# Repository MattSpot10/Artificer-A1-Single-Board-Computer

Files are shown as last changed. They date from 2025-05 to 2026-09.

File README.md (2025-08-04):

# Artificer A1 Single Board Computer
 An open source single board computer with AI capabilities. (Still in progress)

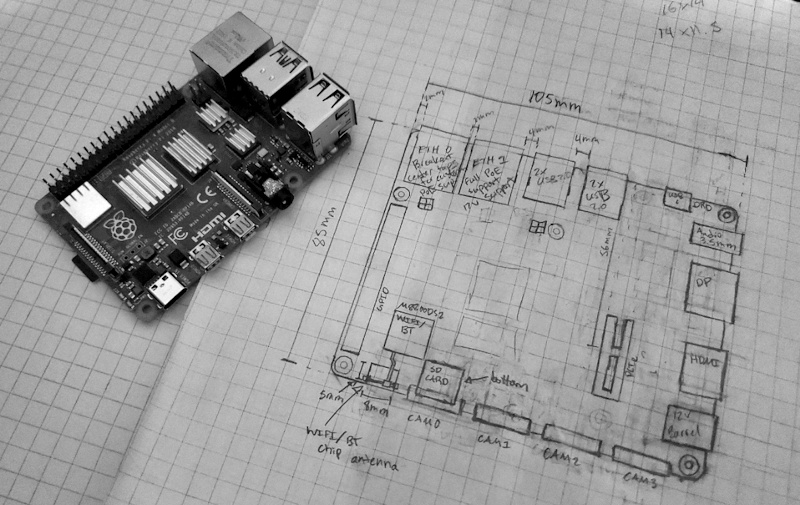
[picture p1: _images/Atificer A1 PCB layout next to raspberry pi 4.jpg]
SBC IMG
 

### **Features/Capabilites
- Alliwnner T527 SoC (Octa-core ARM Cortex-A55, up to 1.8 GHz)
- 4GB LPDDR4 SDRAM
- Dual Gigibit Ethernet (RJ45 ports capable of PoE)
- PCIe gen 2.1
- Display Port, HDMI, 2x4 lane MIPI DSI
- 4x2 lane MIPI CSI
- SD Card as boot media
- M8800DS2 Wifi/BT module with onboard PCB antenna
- 12V 5.5mm barrel jack power input
- 2x20 raspberry pi GPIO header
- 3.5mm sterio audio, mic
- 4xUSBA 2.0
- 1xUSBC 2.0 DRD

### **Progress/Plans (Since Jan 2025)**
**V1 Schematic capture**
- Done: Component choice, symbol, and footprint creation. Finished interconnects for Ethernet, USB, MIPI DSI & CSI, SDRAM, PCIe
- Todo: Interconnects for power, audio, gpio, I2C interfaces, wifi&bt, SD card.
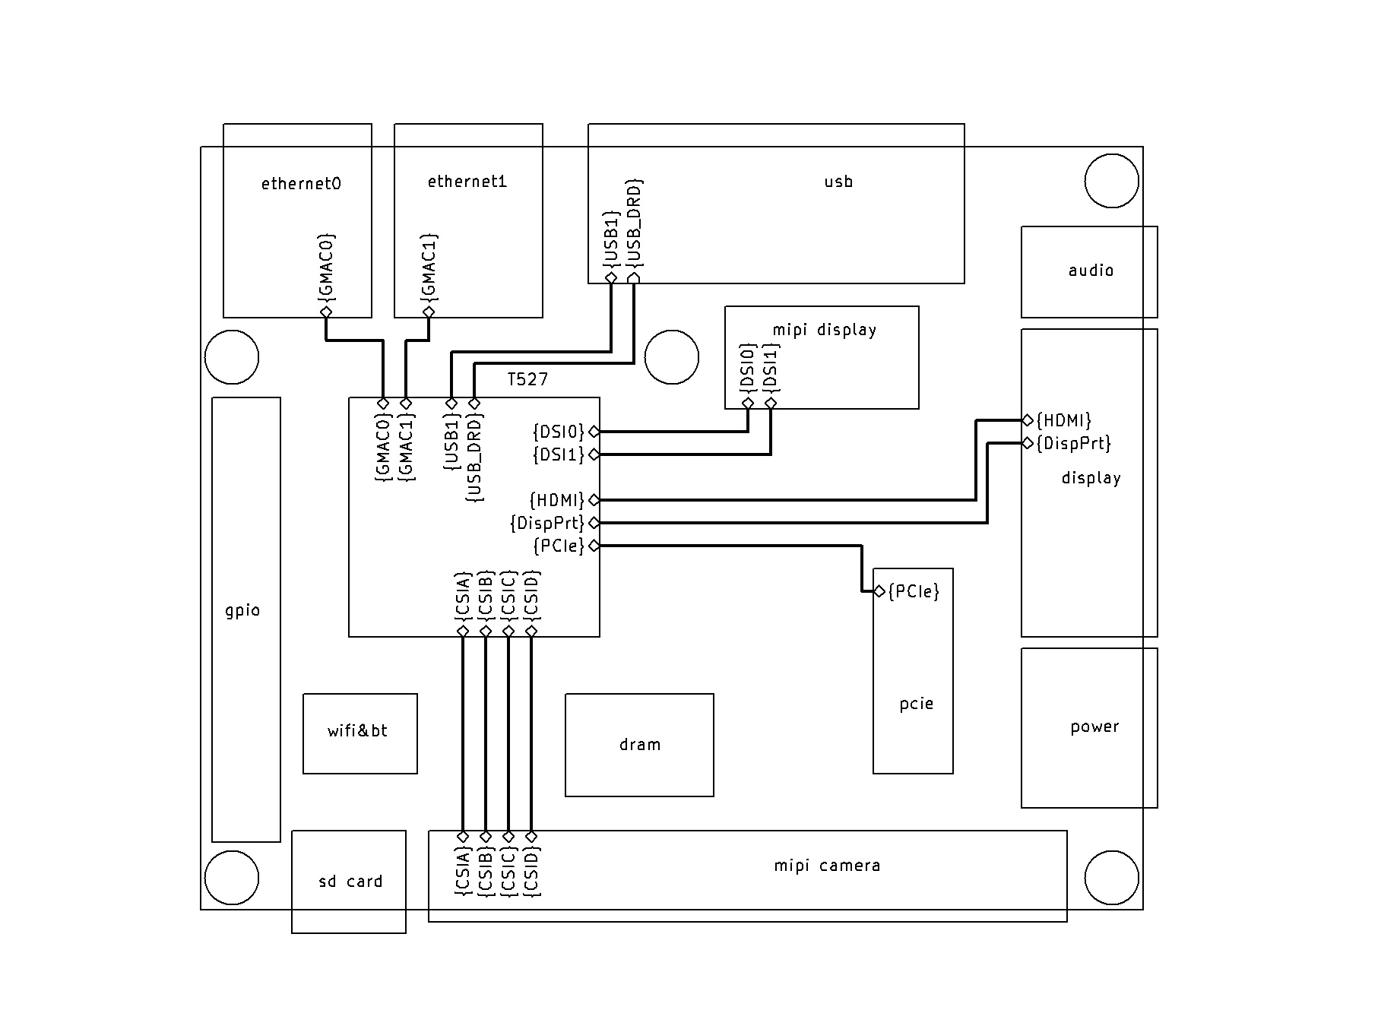
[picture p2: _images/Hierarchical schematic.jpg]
Hierarchical schematic


**PCB Compatabilites**

The Allwinner T527 is a 0.5mm pitch BGA requiring these compatabilities for maufacturing:
- 3mil trace
- 3mil spacing
- 10.685mil pad
- 6mil drill
- 10.685mil pad - 6mil drill = 2.342mil anular ring
- 6 - 8 layers (Stackup and material not determined)

**Booting Linux**
- Add Spi flash chip to schematic for holding U Boot.
- Configure U Boot for loading the Linux kernel and the device tree blob.

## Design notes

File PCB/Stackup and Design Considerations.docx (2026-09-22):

Stackup

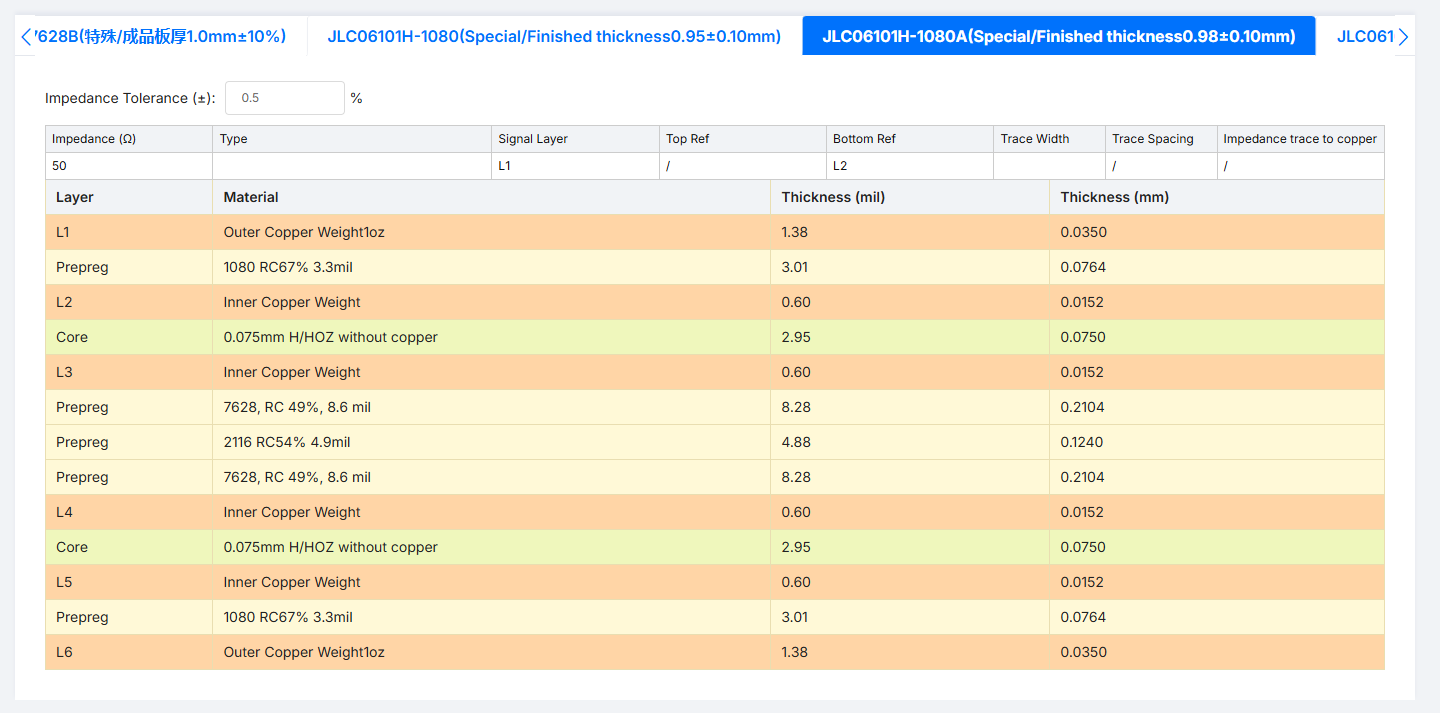
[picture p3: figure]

https://jlcpcb.com/pcb-impedance-calculator

Impedance (Ω) | Purpose | Type | Signal Layer | Top Ref | Bottom Ref | Trace Width | Trace Spacing | Impedance trace to copper
85 | Top Layer 85ohm… | Differential Pair (Non coplanar) | L1 | / | L2 | 4.08 | 4.2 | /
90 | | Differential Pair (Non coplanar) | L1 | / | L2 | 4.05 | 5.5 | /
85 | | Differential Pair (Non coplanar) | L3 | L2 | L5 | 4.03 | 5 | /
50 | | Single Ended (Non coplanar) | L1 | / | L2 | 4.31 | / | /
48.88 | | Single Ended (Non coplanar) | L3 | L2 | L5 | 4 | / | /

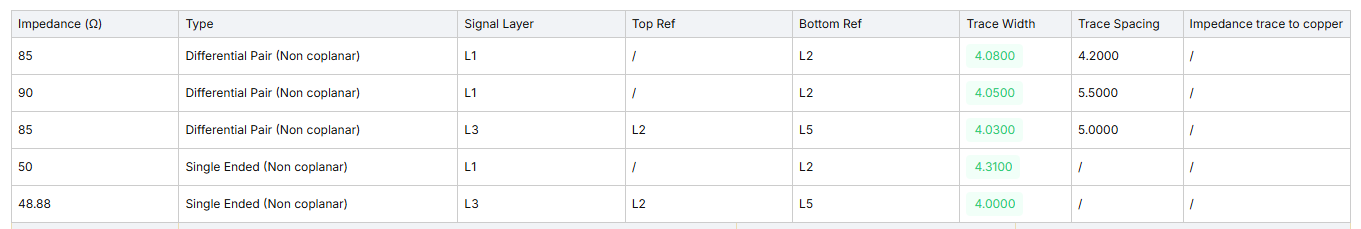
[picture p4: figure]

Protocol | Layer | Trace Width | Trace Spacing | Target Single | Target Diff
MIPI CSI, DSI | L1/L6 | 4.31mil | 6.4mil | 50ohm | 90ohm
USB 3.1, USB 2.0, SuperSpeed & PCIe, HDMI, DP, DDR4 Differential | L1/L6 | 4.02mil | 5.4mil | - | 90ohm
DDR4, RGMII, SDMMC | L1/L6 | 4.31mil | - | 50ohm | -
DDR4, RGMII, SDMMC | L3/L4 | 4.0mil | - | 48.88ohm

Protocol | Layer | Trace Width | Trace Spacing | Target Single | Target Diff
90ohm diff 50ohm single | L1/L6 | 4.31mil | 6.4mil | 50ohm | 90ohm
USB 3.1, USB 2.0, SuperSpeed & PCIe, HDMI, DP, DDR4 Differential | L1/L6 | 4.02mil | 5.4mil | - | 90ohm
DDR4, RGMII, SDMMC | L1/L6 | 4.31mil | - | 50ohm | -
DDR4, RGMII, SDMMC | L3/L4 | 4.0mil | - | 48.88ohm

For non-coplanar keep trace spacing between neighboring traces 3 times the width apart if measuring from the center. This means trace spacing would be equal 2x the trace width.

50ohm single ended non coplanar (top layer):

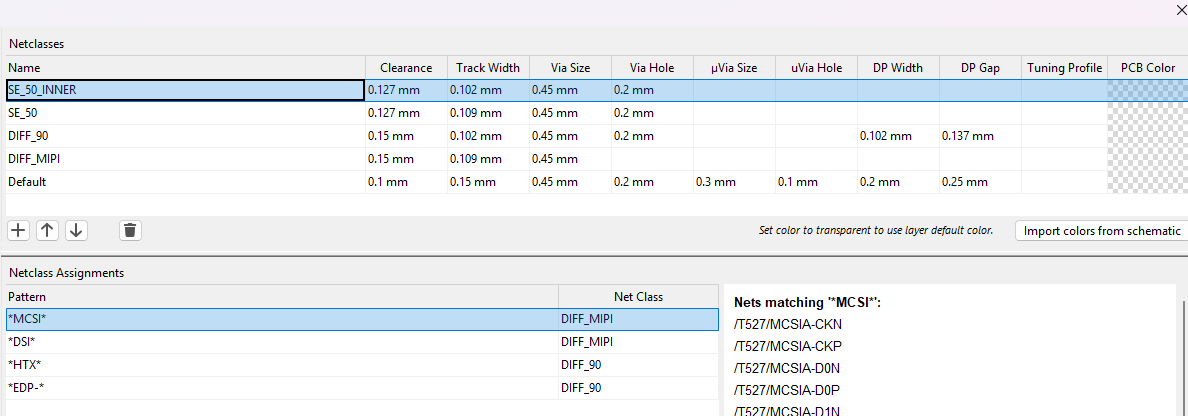
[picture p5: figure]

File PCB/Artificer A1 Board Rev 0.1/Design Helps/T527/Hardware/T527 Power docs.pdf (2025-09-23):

修改记录
版本 | 修改内容 | 日期 | 制/修定人 | 备注
V1.0 | Initial version | 20231031 | AWA1962

## AXP717B+AXP323 For车载后装,商显,工控

CHIP | 编 号 | 分路名称 | INPUT | 电压/电流范围 | 电压 | 启动时序 | 需求电压 （V） | 需求电流 (mA)
（上电默认状 | | | | SOC | Flash & DRAM | DEVICE
| 1 | RTCLDO | 4V-PS | 3.3/1.8/30mA | 1.8V(ON) | 常开 | 1.8 | 10 | VCC-RTC | | | ON | ON | ON
| 2 | CPUSLDO | DCDC3 | 0.5-1.4V/30mA 50mVstep | 0.9V(ON) | 1 | 0.9 | 20 | VDD-CPUS VDD09-USB（预留） | | | ON | ON | OFF | VDD09-USB预留USB STANDBY方 案；
| 3 | DCDC1 | 4V-PS | 0.5~1.54V/4A 10/20mVstep
| | DCDC2 | | 0.5~3.4V/3A 10/20/100mVstep | 0.9V(ON) 0.9V(ON) | 1 1 | 0.9~1.15 0.9 | 4000 2670 | VDD_CPU_L VDD-SYS VDD-HDMI VDD-GPU VDD-VE VDD-DE VDD09-USB VDD-PCIE VDD-EDP | | | ON ON | OFF OFF | OFF 4 OFF | VDD09-USB默认super standby方 案，待机时掉电；
| 5 | DCDC3 | | 0.5~1.84V/1.5A 10/20mVstep | 1.1V(ON) | 1 | 1.1V /1.2/1.35/1.5
| | DCDC4 | | 1~3.7V/3A 100mVstep | 3.3V(OFF) | OFF | 3.3 | 1200 2510 | VCC-DRAM VCC-PD VCC-PE VCC-PK VCC-PJ VCC-PI VCC33-USB-2 (USB3.0) | VCC-DRAM | VCC-3V3 VCC-3V3-WIFI VCC-3V3-PCIE VCC3V3-GPHY LTE-PWR（预留） VCC-CTP VCC-LCD0 VCC-LCD1 VCC-3V3-DEV | ON ON | ON OFF | OFF 6 OFF 3.3V for normal use VCC-3V3下挂 | RS232/RS485/GPS/USBHUB/ DSP/CODEC/EDP/HDMI对片，耗电 约500mA
| | ALDO2 | 固定 4V-PS | 0.5~3.5V/0.4A 100mVstep | 1.8V(OFF) | OFF | / | / | Reserve | | | OFF | OFF | OFF 8
| 7 | ALDO1 ALDO3（该路1% 精度，其他2%） | | 0.5~3.5V/0.5A 100mVstep | 1.8V(OFF) | OFF | / | / | Reserve | | | OFF | OFF | OFF 9
| | | | 0.5~3.5V/0.2A 100mVstep | 3.3V(ON) | 3 | 3.3 | 50 | VCC-PL VCC-PM（预留） VCC33-USB （预留） | | | ON | ON | OFF 3.3V for STBY | VCC33-USB (USB2.0)预留USB standby方案；
| 10 ALDO4（该路1% 精度，其他2%） | | | 0.5~3.5V/0.4A 100mVstep | 1.8V(ON) | 1 | 1.8 | 125 | AVCC VCC-PLL VDD18-DRAM VCC-ADC VCC-DCXO | | | ON | OFF | OFF 1.8V for 1% | ADC接口的VREFP上电时序需晚于或 等于AVCC上电时序。默认方案， VREFP在die内连接到AVCC
| 1.8 v | BLDO1 | 4V-PS | 0.5~3.5V/0.5A 100mVstep | 1.8V(OFF) | OFF | 1.8 | 150 | VCC-PG VCC-PM | | VCCIO-WIFI | ON/OFF OFF | | OFF 12 BLDO2
| | | | 0.5~3.5V/0.2A 100mVstep | 1.8V(ON) | 1 | 1.8 | 20 | | VDD18-LPDDR | | ON | ON | OFF 1.8V for DDR
| 13 BLDO3 | | | 0.5~3.5V/0.5A 100mVstep | 2.8V(OFF) | OFF | 1.8 | 225 | CPVIN VCC-PE（预留） VCC-PD（预留） VCC-PJ（预留） VCC-PK（预留） VCC-MCSI VCC-HDMI VCC18-PCIE VCC18-EDP | | VCC-1V8-AUDIO | ON | OFF | OFF 1.8V for normal use
| 14 BLDO4 | | | 0.5~3.5V/0.4A 100mVstep | 1.2V(OFF) | OFF | 1.8 | 30 | VCC-PL（预留） | | | ON | ON | OFF 1.8V for STBY 15 CLDO1
| | | 4V-PS | 0.5~3.5V/0.5A 100mVstep | 1.8V(ON) | 2 | 1.8 | 450 | VCC-PC VCC-LVDS0 VCC-LVDS1 | VCC-EMMC（预留） VCC-PC(VCCQ- EMMC) | | ON | OFF | OFF 1.8V for normal use
| 16 CLDO2 | | | 0.5~3.5V/0.4A 100mVstep | 3.3V(OFF) | OFF | 1.8 | 105 | VCC-EFUSE | | | OFF | OFF | OFF | EFUSE电源仅可在烧录时打开；
| 17 CLDO3 | | | 0.5~3.5V/0.5A 100mVstep | 3.3V(ON) | 3 | 3.3 | | VCC-IO VCC-PC（预留） VDD33 VCC33-USB | VCC-CARD VCC-SPIFLASH VCC-EMMC VCC-NAND | | OFF | OFF | OFF | VCC33-USB (USB2.0)默认super standby方案，待机时掉电；
| 18 CLDO4 | | | 0.5~3.5V/0.5A 100mVstep | 3.3V(OFF) | OFF | / | / | Reserve | | | OFF | OFF | OFF AW1890 19 集成ALDO
| | (1%精度) | VDD33 | 1.8V | 1.8V(ON) | / | 1.8 | 50 | AVCC（预留） | | | ON | OFF | OFF | SOC内部LDO输出，预留1.8V使用
A X P 3 2 3 | 20 DCDC1 | | 4V-PS | 0.5~3.4V/1.5A 10/20/100mVstep | 0.9(ON) | 1注 | 0.9~1.18 | 4000 | VDD_CPU_B | | | ON | OFF | OFF 21 DCDC2
| | | 4V-PS | 0.5~1.54V/2.5~3A 10/20mVstep | 0.9(ON) | 1注
| 22 DCDC3 | | 4V-PS 4V-PS | 0.5~1.84V/2A 10/20mVstep | 0.9(ON) | 1注 | 0.9 | 1650 | VDD-DNR | | | ON | OFF | OFF 23 RTCLDO
| | | 4V-PS | 1.8V/2.5V/2.8V/3.3V /0.03A | OFF | OFF | | / | | | | ON/OFF OFF | | OFF 24 ALDO1
| | | 4V-PS | 0.5~3.5V/0.3A 100mVstep | 1.8V(OFF) | OFF | 1.8 | / | | | | OFF | OFF | OFF 25 DLDO1
| | | | 0.5~3.5V/0.5A 100mVstep
用途 | Normal Work | Super Standby 关机 | 注释 | 各场景应用说明

A
X
P
7
1
7
3.3V(OFF) | OFF | 3.3 | 350 | VCC-FM | ON/OFF OFF | OFF 以下应用需要需要外挂电源
外挂 电源 | 26 外挂 | Buck5VOUT （SA24403/ SYQA303） | DCIN-12V 4.5~5.5V/3A | 5V(ON) | / | 5 | 3000 | PMU-DCIN VCC-5V（预留） | ON | ON | OFF 27 外挂
| | DCDC5V （SA24403/ SYQA303） | DCIN-12V 5V/3.5A | 5V(ON) | / | 5 | 2000 | VCC-5V AMP-5V HDMI-5V USB-5V | ON | OFF | OFF SER/DES/AMP/CAN
| 28 外挂 | DCDC3.3V （SY8089） | VCC-5V 1.2V/2A | 1.2V(ON) | / | 1.2 | 1000 | DVDD-1V2-CSI0 DVDD-1V2-CSI1 AVDD-1V2-CSI0 AVDD-1V2-CSI1 | ON | OFF | OFF 29 外挂
| | DCDC3.8V （SA24403/ SYQA303） | DCIN-12V 3.3V/3.5A | 3.3V(OFF) | / | 3.3/3.8 | 1000 | LTE-PWR | ON | OFF | OFF 4G模块
| 30 外挂 | LDO1.8V /SGM2028-ADJ) (RY6211B-18C | LTE-PWR 1.8V/0.5A | 1.8V(OFF) | / | 1.8 | 100 | VCC-LTE18 | ON | OFF | OFF 4G模块
| 31 外挂 | LDO3.3V （mpq2029） | DCIN-12V 3.3V/0.45A | 3.3V(ON) | / | 3.3 | 100 | 3V3-STBY (VCC-MCU) | ON | ON | ON | 3V3-STBY 32 外挂
| | LDO1.8V /SGM2028-ADJ) (RY6211B-18C | 3V3-STBY 1.8V/0.5A | 1.8V(ON) | / | 1.8 | 10 | 1V8-STBY
(VCC-RTC) | ON | ON | ON | 1V8-STBY 注：AXP323上电使能是由AXP717B-BLDO2提供，该时序为AXP323使能之后的启动时序

注：灰色字体的电源代表预留方案

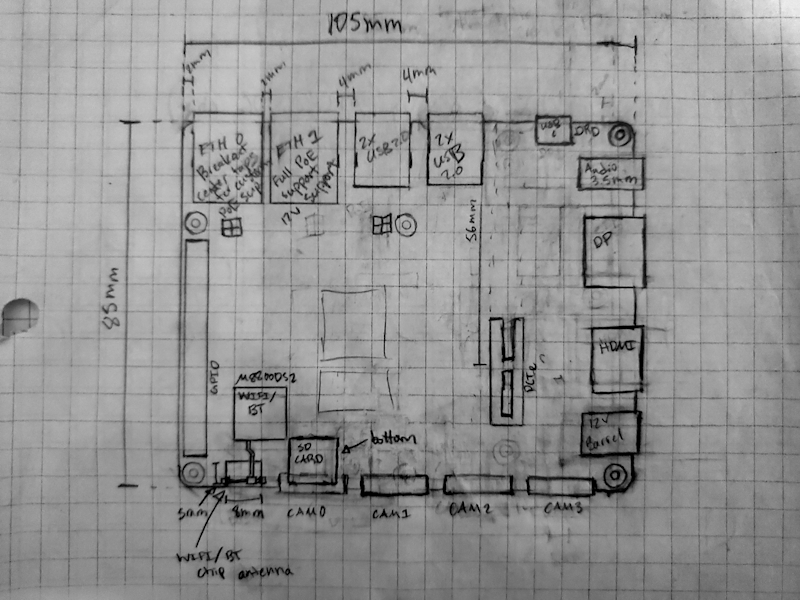
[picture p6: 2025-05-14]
_images/Atificer A1 PCB layout.jpg

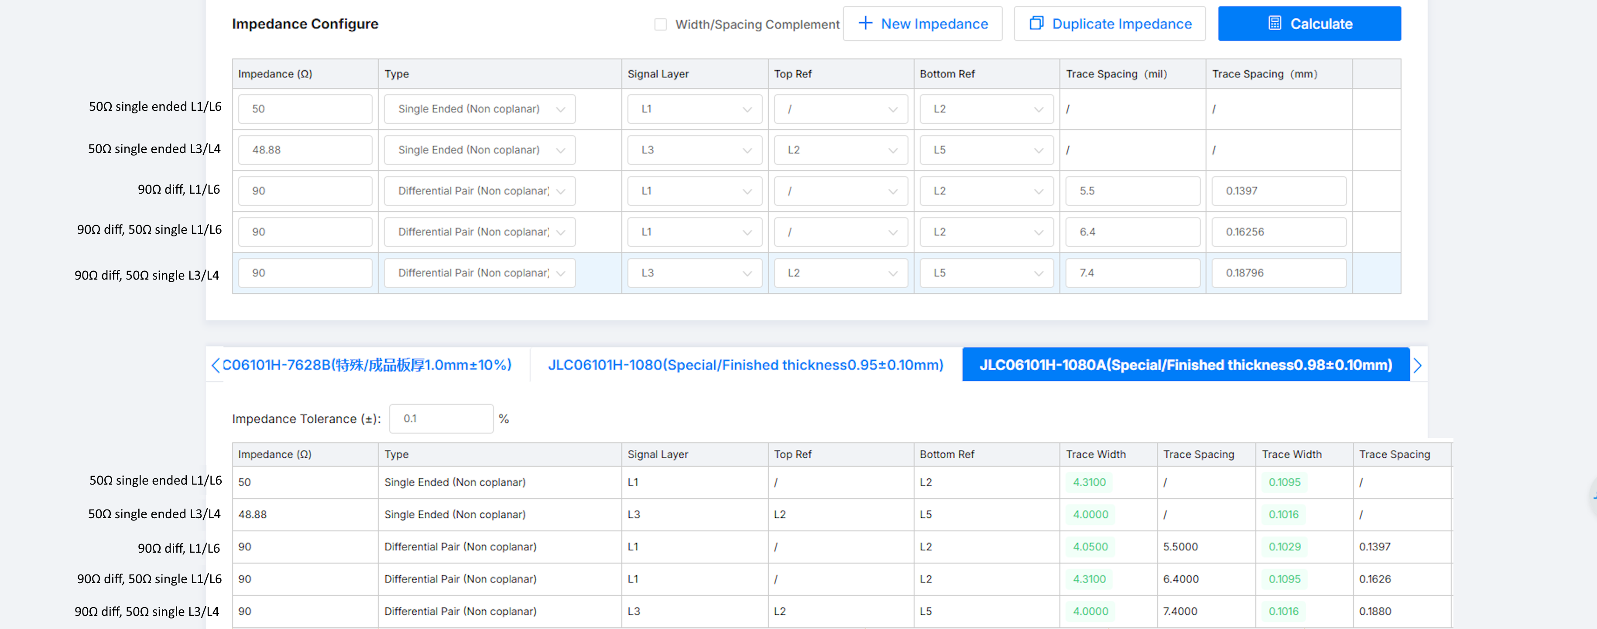
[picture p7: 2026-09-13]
PCB/Impedance-2.png

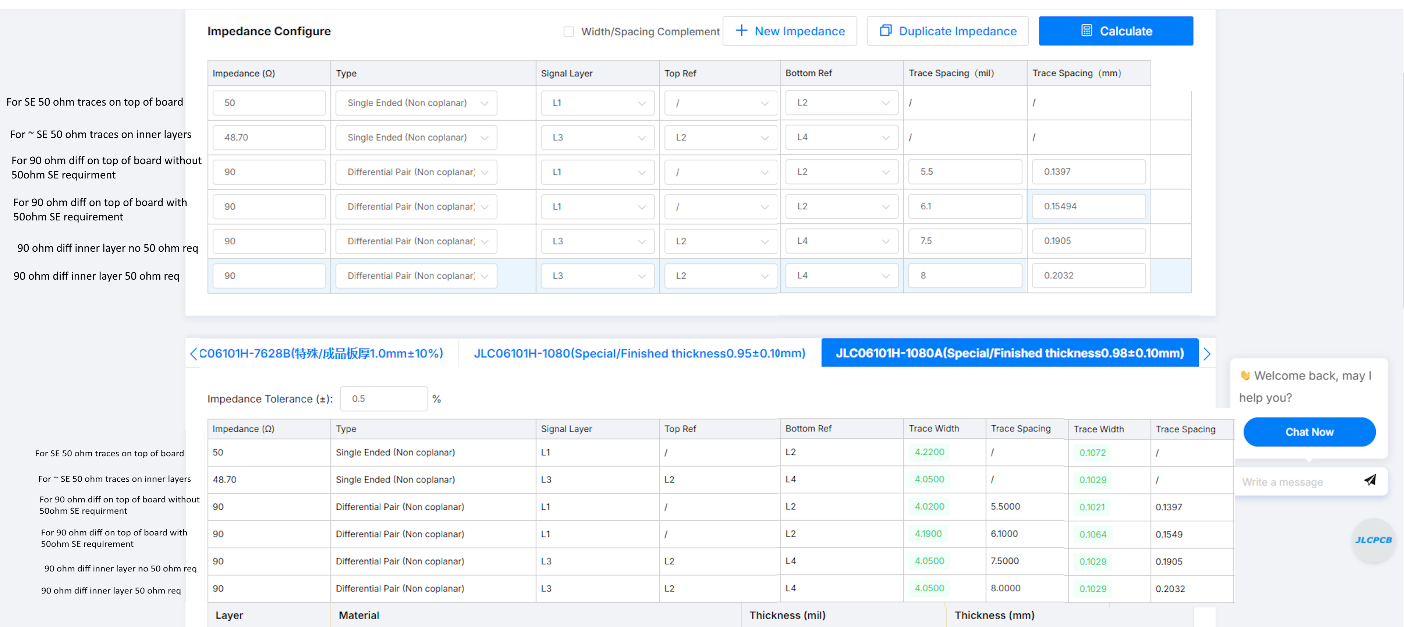
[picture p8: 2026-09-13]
PCB/Impedance.png

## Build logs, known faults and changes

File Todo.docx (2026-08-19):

Connect TWI interfaces: Camera, PMIC, Display, GPIO

Connect UART interfaces: USB C, GPIO

Figure out Headphone usage.

Figure out what to do with unused pins.

Find out impedance values for high-speed traces and place that on the schematic

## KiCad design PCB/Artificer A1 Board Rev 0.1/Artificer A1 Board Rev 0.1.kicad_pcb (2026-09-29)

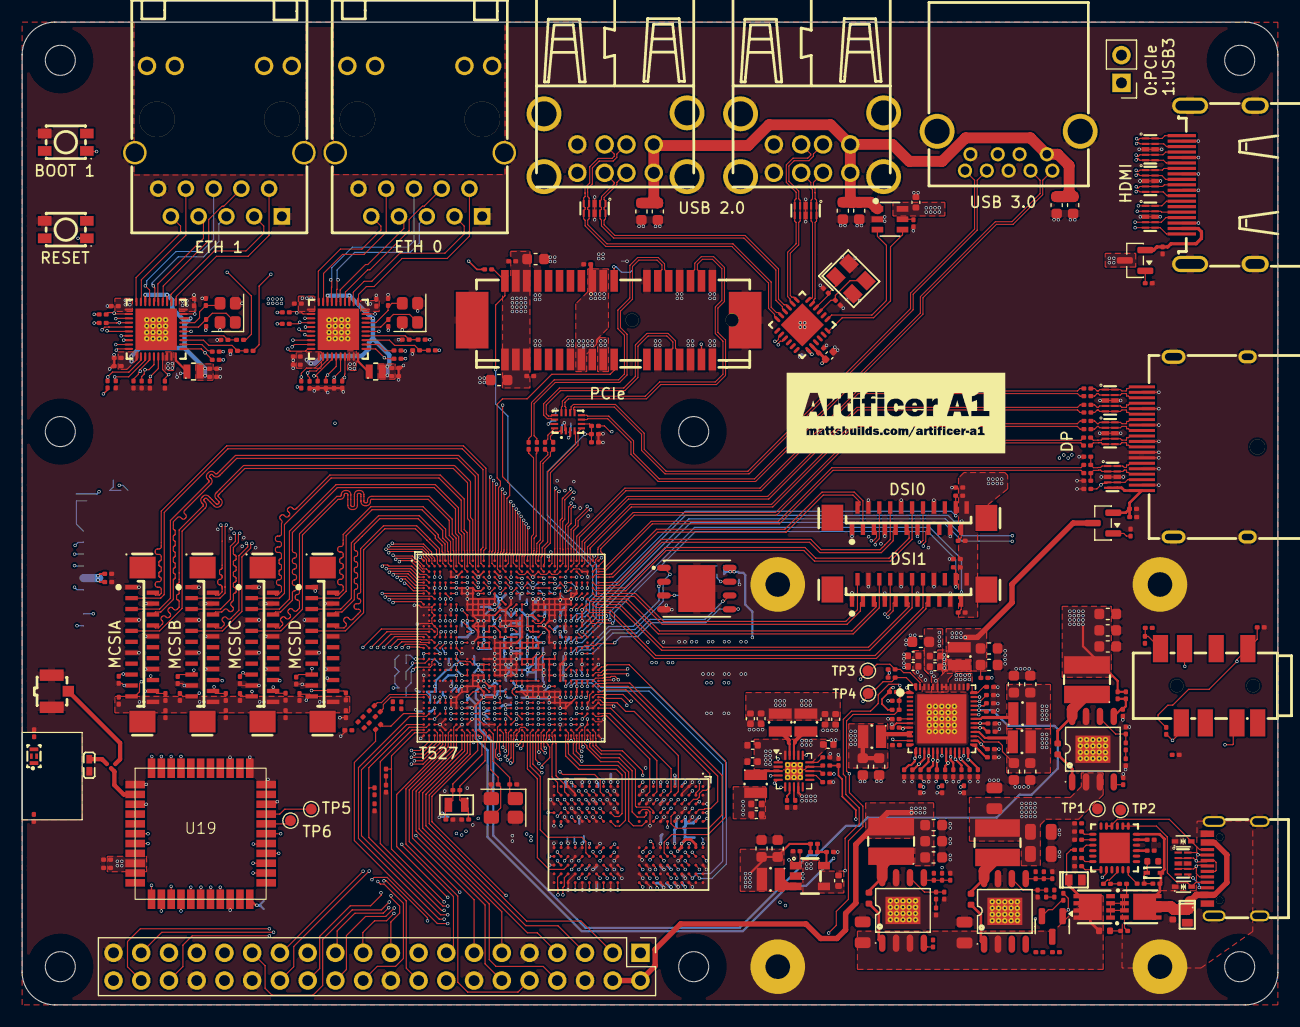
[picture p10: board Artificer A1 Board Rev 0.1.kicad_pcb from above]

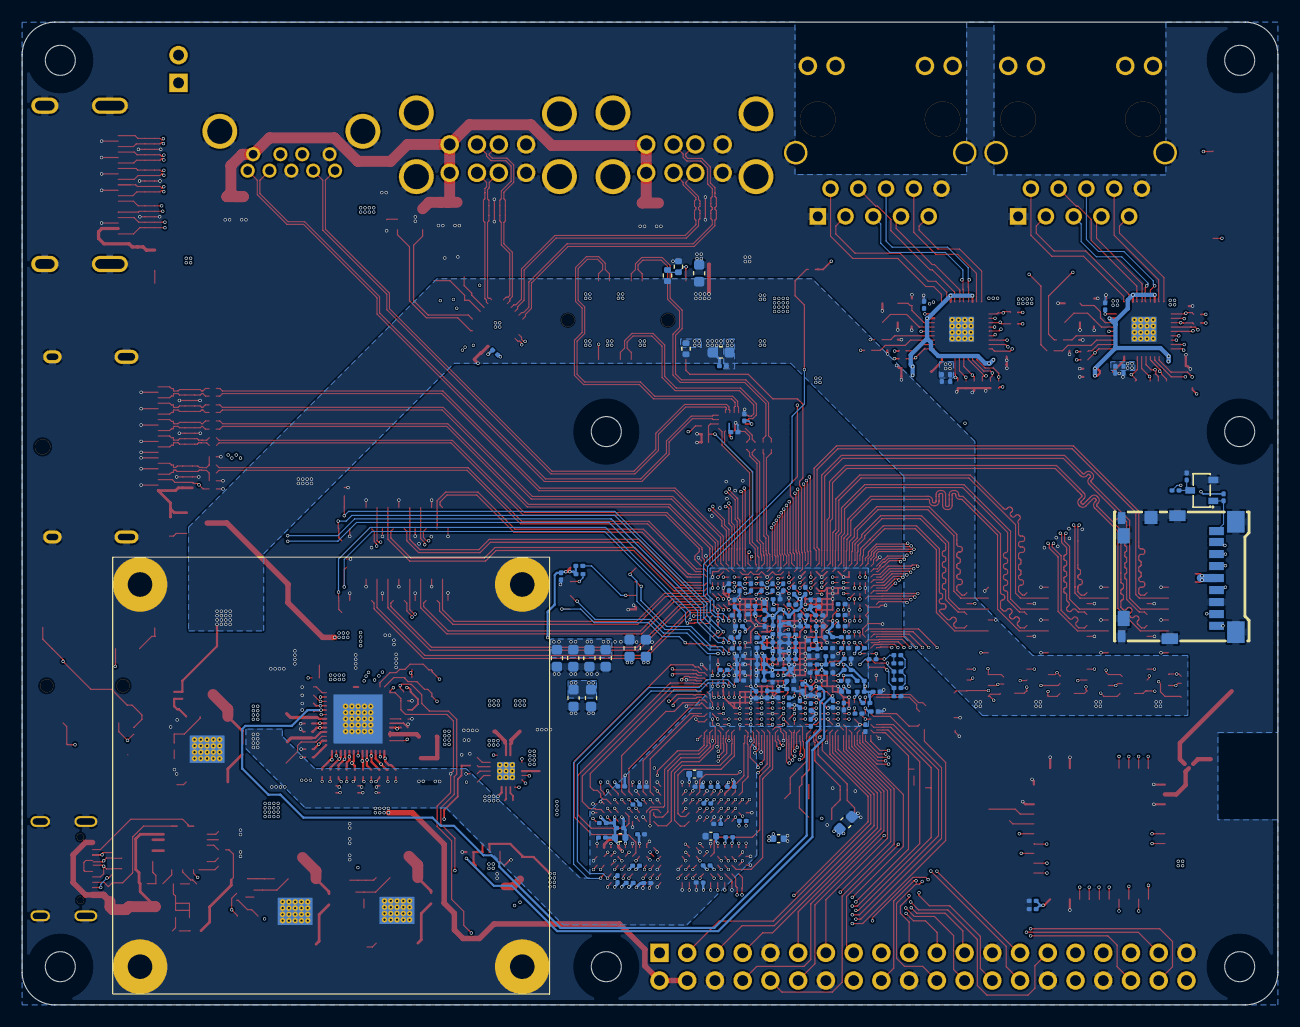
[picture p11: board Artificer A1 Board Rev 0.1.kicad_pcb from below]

Board: 6 copper layers, 115.0 x 90.0 mm, 503 parts (157 on the bottom side), 489 nets.

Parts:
C1, C14, C15: 10uF; C_0805
C2, C9, C16, C17: 100nF; C_0402
C3, C13: 1uF; C_0402
C25, C27: 22uF; C_0805
C85, C86, C87, C88, C133, C134, C135, C136, C137, C138, C139, C140, C141, C142, C143, C151, C154, C158, C159, C160, C161, C164, C165, C167, C168, C170, C171, C172, C173, C174, C175, C176, C177, C178, C181, C183, C184, C185, C186, C187, C189, C191, C193, C199, C200, C207, C208, C211, C212, C213, C214, C300, C301, C309, C320, C321, C322, C323, C344, C345, C346, C347, C356, C358, C359, C360, C363, C364, C365, C375, C376, C383, C384, C392, C393, C398, C403, C406, C408, C410, C411, C412, C413, C414, C415, C416, C418, C419, C420, C421, C422, C423, C424, C426, C427, C428: 100nF; C_0201_0603Metric
C162, C163: 10nF; C_0201_0603Metric
C166, C169, C209, C210, C221, C222, C223, C224, C225, C226, C227, C228, C229, C230, C241, C253, C254, C255, C270, C271, C282, C285, C286, C287, C288, C308, C310, C311, C312, C313, C314, C315, C316, C317, C318, C319, C328, C329, C330, C331, C332, C333, C334, C335, C336, C337, C341, C342, C348, C350, C351, C352, C353, C379, C380, C381, C386, C388, C390, C391, C395, C396, C397, C400, C401, C402, C404, C405, C425: 2.2uF; C_0201_0603Metric
C179, C180, C233, C234, C235, C236, C237, C238, C239, C240, C242, C261, C262, C263, C264, C265, C266, C268, C283, C284, C292, C293, C294, C295, C296, C297, C302, C303, C354, C377, C378, C385, C387, C389, C394, C399: 22uF; C_0603_1608Metric
C182, C188, C205, C291: 22pF; C_0201_0603Metric
C190, C192, C194, C219, C220, C231, C232, C247, C248, C249, C250, C251, C252, C257, C267, C272, C374, C382, C407, C409, C417: 1uF; C_0201_0603Metric
C195, C197, C289: 3.3nF; C_0201_0603Metric
C196, C204, C290: 47pF; C_0201_0603Metric
C198, C202: 33pF; C_0201_0603Metric
C201: 1nF; C_0201_0603Metric
C215, C216, C217, C218: 6pF; C_0201_0603Metric
C243, C244, C245, C246, C256, C269, C273, C274, C275, C276, C277, C278, C324, C325, C326, C327: 10uF; C_0402_1005Metric
C258: 1uF; C_0402_1005Metric
C259, C260: 4pF; C_0201_0603Metric
C279, C280, C281: 4.7uF; C_0402_1005Metric
C298: 6.2pF; C_0201_0603Metric
C299: 0.4pF; C_0201_0603Metric
C304, C305, C306, C307: 12pF; C_0201_0603Metric
C338, C339, C340: 470nF; C_0201_0603Metric
CN3: PJ-393-8P_C49284725; AUDIO-TH_PJ-393-8P
Card1: TF-110; TF-SMD_TF-110
D1, D3: ESDA25P35-1U1M-ES; DFN1610-2L_L1.6-W1.0-P1.10-RD
D4, D5, D6, D7, D8, D9, D10, D11, D13: RClamp0524PATCT; SLP2510P8_L2.5-W1.0-P0.50-BL
D12, D14: LESD5D5.0CT1G_C5199850; SOD-523_L1.2-W0.8-LS1.6-BI
D15: B5819WT_C7502714; SOD-523_L1.2-W0.8-LS1.6-RD
DP1: CAR06-201EN5F; DP-SMD_CAR06-201EN5F
FPC1, FPC2: 0.5K-A-22PB; FPC-SMD_22P-P1.00_0.5K-A-22PB
H1, H1#2, H2, H3, H4, H5, H6: MountingHole; NP-mounting-hole
HDMI1: HD-A-05H9191N; HDMI-SMD_HD-A-05H9192N
J1: Conn_02x20_Odd_Even; PinHeader_2x20_P2.54mm_Vertical
J2: Conn_01x02; PinHeader_1x02_P2.54mm_Vertical
JP1: U.FL-R-SMT-1(80); RF-SMD_FRF05002-JSS103M
L2, L16: 3.3uH MTQH404020S3R3MBT; IND-SMD_L4.1-W4.1_MTQH404020S
L3, L4, L5, L6, L7, L8, L9, L10: APH252012C1R0MP01; IND-SMD_APH252012C3R3MP01
L11, L12: APH141208C2R2MP01; IND-SMD_L1.4-W1.2_AOTA-B141206SR47MT
L13: ANT162442DT-2001A2; ANT-SMD_6P-L1.6-W0.8-L
L14: MLG1005S1N3BT000; L0402
L15: 10uH MTQH404030S100MBT; IND-SMD_L4.1-W4.1_MTQH404030S
M1: Fan&Heatsink_40x40mm; custom_heatsink&fan_40x40mm
Q1, Q2: AON3419-TP; DFN-8_L3.0-W3.0-P0.65-BL
Q3: AO3401A; Q_SOT-23
Q4: 2SK3018; SOT-23-3_L2.9-W1.4-P1.90-LS2.6-BR
Q6, Q7: AO3401A; SOT-23
R107, R108, R168, R176, R199, R202, R204, R205, R209, R210, R211, R212, R213, R214, R230, R231: 10k; R_0201_0603Metric
R109, R110, R111, R158, R162, R163, R164, R165, R166, R169, R170, R171, R172, R174, R184, R185, R195, R198, R240: 100k; R_0201_0603Metric
R112, R113: 2.49k; R_0201_0603Metric
R114, R115, R116, R117, R118, R119, R120, R121, R122, R123, R124, R125, R126, R127, R128, R129, R130, R131, R132, R133, R134, R135, R136, R137, R215, R216, R217, R218, R219, R220, R221, R222, R223, R224, R225, R226, R227, R228: 4.7k; R_0201_0603Metric
R144, R145, R146, R147, R156: 470; R_0201_0603Metric
R148, R149, R150, R154, R157, R161, R173, R196, R197, R233, R234: 1k; R_0201_0603Metric
R151, R152, R153: 200; R_0201_0603Metric
R155: 39k; R_0201_0603Metric
R159: 100; R_0201_0603Metric
R160: 22k; R_0201_0603Metric
R167, R175, R229, R232, R237: 0Ω; R_0201_0603Metric
R177: 120Ω; R_0201_0603Metric
R178, R179: 240Ω; R_0201_0603Metric
R180: 51k; R_0201_0603Metric
R181: 6.3k; R_0201_0603Metric
R182, R189, R190: 200k; R_0201_0603Metric
R183, R186, R191: 14k; R_0201_0603Metric
R187: 75k; R_0201_0603Metric
R188: 24k; R_0201_0603Metric
R192: 27k; R_0201_0603Metric
R193: 5.1k; R_0201_0603Metric
R194: 0Ω; RF_Select_0201_L_Shape
R200, R201: 10k; R_0402_1005Metric
R203: 0Ω; R_0402_1005Metric
R206: 10M; R_0201_0603Metric
R207: 4.3k; R_0201_0603Metric
R208: 6.8k; R_0201_0603Metric
R235: 2k; R_0201_0603Metric
R236: 47k; R_0201_0603Metric
R238, R239: 22Ω; R_0201_0603Metric
RJ1, RJ2: HR911130A; RJ45-TH_HR911130A
SW1: BOOT1; SW-SMD_4P-L3.5-W3.0-P1.50-LS4.7
SW2: RESET; SW-SMD_4P-L3.5-W3.0-P1.50-LS4.7
TP1, TP2: TestPoint; TestPoint_Pad_D1.0mm
TP3, TP4: DCDC1; TestPoint_Pad_D1.0mm
TP5: BT-UART0_RX; TestPoint_Pad_D1.0mm
TP6: BT-UART0_TX; TestPoint_Pad_D1.0mm
U1: GT-USB-7010ASV; USB-C-SMD_G-SWITCH_GT-USB-7010ASV
U2: GD25LQ128EWIGR; WSON-8_L6.0-W5.0-P1.27-BL-EP
U3, U6: AP64500SP-13; SO-8_L4.9-W3.9-P1.27-LS6.0-BL-EP
U4: STUSB4500QTR; QFN-24_L4.0-W4.0-P0.50-BL-EP2.8
U5: AP64350SP-13; SO-8_L4.9-W3.9-P1.27-LS6.0-BL-EP
U8: T527M00X0DCH; BGA-664_L17.0-W17.0_T527
U9: SY8089A1AAC; TSOT-23-5_L2.9-W1.6-P0.95-LS2.8-BR
U10: AXP717B; QFN-52_L6.0-W6.0-P0.40-TL-EP4.5
U11: AXP323
U12: K4UBE3D4AB-MGCL; FBGA-200_L14.5-W10.0_RS1G32LF4D2BDS-53BT
U13, U24, U25, U26: AFC11-S22ICA-00; FPC-SMD_22P-P1.00_AFC11-S22ICC-00
U14, U15: RTL8211F-CG; WQFN-40_L5.0-W5.0-P0.4-BL-EP
U16: HD3SS3202IRSVR; UQFN-16_L2.6-W1.8-P0.40-BL
U17: X3113WVS-36-9TV01; CONN-SMD_X3113WVS-36-9TV01
U19: M8800DS2-40
U21: CH217K; SOT-23-6_L2.9-W1.6-P0.95-LS2.8-BL
U22: CH334F_C5187527; QFN-24_L4.0-W4.0-P0.50-BL-EP2.8
USB1, USB2: Double layer DIP 90° black; USB-A-TH_USB-M-51
USB4: HC-USB3.0-L168-WJ; USB-3.0-A-TH_HC-USB3.0-L168-WJ
X1, X2: 25MHz; Crystal_SMD_2520-4Pin_2.5x2.0mm
X3: SMD-3225_4P12M12PF10PPM; CRYSTAL-SMD_4P-L3.2-W2.5-BL
X4: 25MHz; Crystal_SMD_3225-4Pin_3.2x2.5mm
X5: SC-20S32.768kHz20PPM9pF; OSC-SMD_L2.0-W1.2

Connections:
5V_SYS: C231.2, C232.2, C245.2, C246.2, C247.2, C251.2, C252.2, C257.2, C258.2, C267.2, C291.2, C295.2, C296.2, C297.2, J1.2, J1.4, L16.2, Q3.2 (S), Q6.3 (D), R184.1, R192.2, U10.9 (VIN1), U10.15 (ALDOIN), U10.20 (BLDOIN), U10.25 (CLDOIN), U10.31 (VIN3), U10.32 (VIN2), U10.49 (VBUS_1), U10.50 (VBUS_2), U21.6 (VIN), U22.19 (V5)
323-ALDO1: C241.2, U11.15 (ALDO1)
323-DCDC1/2: C275.2, C276.2, C277.2, C278.2, C282.2, C283.2, C284.2, C285.2, C286.2, C374.2, C375.2, C376.2, L8.2, L9.2, U8.T19 (VDDCPUB), U8.T21 (VDDCPUB), U8.T22 (VDDCPUB), U8.U18 (VDDCPUB), U8.U19 (VDDCPUB), U8.U21 (VDDCPUB), U8.U22 (VDDCPUB)
323-DCDC3: C273.2, C274.2, C399.2, C400.2, C401.2, C402.2, C403.2, C404.2, L10.2, U8.AA12 (VDDDNR), U8.AA13 (VDDDNR), U8.Y12 (VDDDNR), U8.Y13 (VDDDNR)
323-DLDO1: C270.2, U11.12 (DLDO1)
323-RTCLDO: C271.2, U11.7 (RTCLDO)
+12V: C15.1, C25.1, C27.1, C172.2, C178.2, C179.2, C180.2, C188.2, L15.2, R180.2, U6.2 (VIN), U6.3 (EN), U17.2 (A2_+12V), U17.3 (A3_+12V), U17.19 (B1_+12V), U17.20 (B2_+12V), U17.21 (B3_+12V)
/ETH0.RGMII-CLKIN: U8.C17 (PH3), U14.35 (CLKOUT)
/ETH0.RGMII-INTB: R126.2, U8.B15 (PH13), U14.31 (INTB/PMEB)
/ETH0.RGMII-MDC: U8.C16 (PH9), U14.13 (MDC)
/ETH0.RGMII-MDIO: R130.2, U8.B16 (PH10), U14.14 (MDIO)
/ETH0.RGMII-PHYRSTB: R128.2, U8.D16 (PH8), U14.12 (PHYRSTB)
/ETH0.RGMII-RXCK: R116.1, U8.B14 (PH16), U14.27 (PHYAD1/RXC)
/ETH0.RGMII-RXCTL: R118.1, U8.D18 (PH2), U14.26 (PHYAD2/RXCTL)
/ETH0.RGMII-RXD0: R134.1, U8.E18 (PH1), U14.25 (RXDLY/RXD0)
/ETH0.RGMII-RXD1: R132.1, U8.F18 (PH0), U14.24 (TXDLY/RXD1)
/ETH0.RGMII-RXD2: R136.1, U8.D14 (PH15), U14.23 (PLLOFF/RXD2)
/ETH0.RGMII-RXD3: R114.2, U8.E14 (PH14), U14.22 (PHYAD0/RXD3)
/ETH0.RGMII-TXCK: U8.G12 (PH6), U14.20 (TXC)
/ETH0.RGMII-TXCTL: U8.F14 (PH7), U14.19 (TXCTL)
/ETH0.RGMII-TXD0: U8.E16 (PH5), U14.18 (TXD0)
/ETH0.RGMII-TXD1: U8.B17 (PH4), U14.17 (TXD1)
/ETH0.RGMII-TXD2: U8.A14 (PH18), U14.16 (TXD2)
/ETH0.RGMII-TXD3: U8.B13 (PH17), U14.15 (TXD3)
/ETH1.RGMII-CLKIN: U8.E2 (PJ3), U15.35 (CLKOUT)
/ETH1.RGMII-INTB: R127.2, U8.J1 (PJ16), U15.31 (INTB/PMEB)
/ETH1.RGMII-MDC: U8.H2 (PJ8), U15.13 (MDC)
/ETH1.RGMII-MDIO: R131.2, U8.H3 (PJ9), U15.14 (MDIO)
/ETH1.RGMII-PHYRSTB: R129.2, U8.G4 (PJ10), U15.12 (PHYRSTB)
/ETH1.RGMII-RXCK: R117.1, U8.J5 (PJ13), U15.27 (PHYAD1/RXC)
/ETH1.RGMII-RXCTL: R119.1, U8.E1 (PJ2), U15.26 (PHYAD2/RXCTL)
/ETH1.RGMII-RXD0: R135.1, U8.D2 (PJ1), U15.25 (RXDLY/RXD0)
/ETH1.RGMII-RXD1: R133.1, U8.D1 (PJ0), U15.24 (TXDLY/RXD1)
/ETH1.RGMII-RXD2: R137.1, U8.J4 (PJ12), U15.23 (PLLOFF/RXD2)
/ETH1.RGMII-RXD3: R115.2, U8.G5 (PJ11), U15.22 (PHYAD0/RXD3)
/ETH1.RGMII-TXCK: U8.G1 (PJ6), U15.20 (TXC)
/ETH1.RGMII-TXCTL: U8.G2 (PJ7), U15.19 (TXCTL)
/ETH1.RGMII-TXD0: U8.F2 (PJ5), U15.18 (TXD0)
/ETH1.RGMII-TXD1: U8.F1 (PJ4), U15.17 (TXD1)
/ETH1.RGMII-TXD2: U8.L5 (PJ15), U15.16 (TXD2)
/ETH1.RGMII-TXD3: U8.L4 (PJ14), U15.15 (TXD3)
/T527/AP-WAKE-BT: U8.AN2 (PM1), U19.6 (HOST_WAKE_BT)
/T527/AP-WAKE-WL: U8.AM4 (PM2), U19.24 (HOST_WAKE_WL)
/T527/BOOT_SEL_ADC: R207.2, R208.1, U8.W1 (GPADC0)
/T527/BT-PCM-CLK: U8.U4 (PG11), U19.26 (PCM_CLK)
/T527/BT-PCM-DIN: U8.U1 (PG14), U19.25 (PCM_DOUT)
/T527/BT-PCM-DOUT: U8.U2 (PG13), U19.27 (PCM_DIN)
/T527/BT-PCM-SYNC: U8.U3 (PG12), U19.28 (PCM_FSYNC)
/T527/BT-UART-CTS: U8.U6 (PG9), U19.41 (UART1_RTS)
/T527/BT-UART-RTS: U8.R4 (PG8), U19.44 (UART1_CTS)
/T527/BT-UART-RX: U8.R5 (PG7), U19.42 (UART1_TX)
/T527/BT-UART-TX: U8.R6 (PG6), U19.43 (UART1_RX)
/T527/BT-WAKE-AP: U8.AN3 (PM0), U19.7 (BT_WAKE_HOST)
/T527/DBG_DN: D13.4 (IN3), D13.7 (NC), U1.A7 (DN1), U1.B7 (DN2), U8.B24 (USB0-DM)
/T527/DBG_DP: D13.2 (IN2), D13.9 (NC), U1.A6 (DP1), U1.B6 (DP2), U8.A24 (USB0-DP)
/T527/DBG_UART0_RX: D13.5 (IN4), D13.6 (NC), U1.B8 (SBU2), U8.R29 (PB10)
/T527/DBG_UART0_TX: D13.1 (IN1), D13.10 (NC), U1.A8 (SBU1), U8.R28 (PB9)
/T527/DDR-PARA-SEL-ADC1: R209.1, R210.2, U8.W2 (GPADC1)
/T527/DDR-PARA-SEL-ADC2: R211.2, R212.1, U8.W3 (GPADC2)
/T527/DSI0-CKN: FPC1.8, U8.E33 (PD5)
/T527/DSI0-CKP: FPC1.9, U8.E32 (PD4)
/T527/DSI0-D0N: FPC1.2, U8.D33 (PD1)
/T527/DSI0-D0P: FPC1.3, U8.D32 (PD0)
/T527/DSI0-D1N: FPC1.5, U8.E31 (PD3)
/T527/DSI0-D1P: FPC1.6, U8.E30 (PD2)
/T527/DSI0-D2N: FPC1.11, U8.F33 (PD7)
/T527/DSI0-D2P: FPC1.12, U8.F32 (PD6)
/T527/DSI0-D3N: FPC1.14, U8.G31 (PD9)
/T527/DSI0-D3P: FPC1.15, U8.G30 (PD8)
/T527/DSI1-CKN: FPC2.8, U8.J30 (PD15)
/T527/DSI1-CKP: FPC2.9, U8.J29 (PD14)
/T527/DSI1-D0N: FPC2.2, U8.G33 (PD11)
/T527/DSI1-D0P: FPC2.3, U8.G32 (PD10)
/T527/DSI1-D1N: FPC2.5, U8.H32 (PD13)
/T527/DSI1-D1P: FPC2.6, U8.H31 (PD12)
/T527/DSI1-D2N: FPC2.11, U8.J33 (PD17)
/T527/DSI1-D2P: FPC2.12, U8.J32 (PD16)
/T527/DSI1-D3N: FPC2.14, U8.K32 (PD19)
/T527/DSI1-D3P: FPC2.15, U8.K31 (PD18)
/T527/DXIN: C304.2, U8.AM13 (DXIN), X4.1
/T527/DXOUT: C305.2, U8.AN13 (DXOUT), X4.3
/T527/Disp0-SCL: FPC1.20, R223.2, U8.R30 (PB11)
/T527/Disp0-SDA: FPC1.21, R224.2, U8.R31 (PB12)
/T527/Disp1-SCL: FPC2.20, R225.2, U8.L31 (PD22)
/T527/Disp1-SDA: FPC2.21, R226.2, U8.L32 (PD23)
/T527/EDP-AUXN: C208.1, U8.C33 (EDPAUXN)
/T527/EDP-AUXP: C207.1, U8.C32 (EDPAUXP)
/T527/EDP-HPD: D9.4 (IN3), D9.7 (NC), DP1.18 (HOT_PLUG), R109.1, U8.C29 (EDPHPD)
/T527/EDP-TX0N: C135.1, U8.B29 (EDPTX0N)
/T527/EDP-TX0P: C134.1, U8.A29 (EDPTX0P)
/T527/EDP-TX1N: C137.1, U8.B30 (EDPTX1N)
/T527/EDP-TX1P: C136.1, U8.A30 (EDPTX1P)
/T527/EDP-TX2N: C139.1, U8.B31 (EDPTX2N)
/T527/EDP-TX2P: C138.1, U8.A31 (EDPTX2P)
/T527/EDP-TX3N: C141.1, U8.B33 (EDPTX3N)
/T527/EDP-TX3P: C140.1, U8.B32 (EDPTX3P)
/T527/FEL: SW1.1, U8.F16 (FEL)
/T527/HBIAS: C353.2, R235.1, U8.AL1 (HBIAS)
/T527/HCEC: D6.1 (IN1), D6.10 (NC), HDMI1.13 (CEC), U8.E28 (HCEC)
/T527/HHPD: D6.5 (IN4), D6.6 (NC), HDMI1.19 (HOT_PLUG_DET), U8.D28 (HHPD)
/T527/HP-DET: R236.2, U8.AJ2 (HPDET)
/T527/HPOUTFB: C198.1, C202.2, CN3.4, R234.1, R237.1, U8.AM1 (HPOUTFB)
/T527/HPOUTL: C174.2, CN3.6, U8.AL2 (HPOUTL)
/T527/HPOUTR: C175.2, CN3.3, U8.AM2 (HPOUTR)
/T527/HS-MIC: C198.2, C201.2, CN3.1, R154.2, R233.1, R235.2
/T527/HSCL: D6.2 (IN2), D6.9 (NC), HDMI1.15 (I2C-CLK), U8.D26 (HSCL)
/T527/HSDA: D6.4 (IN3), D6.7 (NC), HDMI1.16 (I2C_DATA), U8.E26 (HSDA)
/T527/HTX0N: D5.2 (IN2), D5.9 (NC), HDMI1.9 (D0-), U8.C27 (HTX0N)
/T527/HTX0P: D5.1 (IN1), D5.10 (NC), HDMI1.7 (D0+), U8.B27 (HTX0P)
/T527/HTX1N: D4.5 (IN4), D4.6 (NC), HDMI1.6 (D1-), U8.B26 (HTX1N)
/T527/HTX1P: D4.4 (IN3), D4.7 (NC), HDMI1.4 (D1+), U8.A26 (HTX1P)
/T527/HTX2N: D4.2 (IN2), D4.9 (NC), HDMI1.3 (D2-), U8.C25 (HTX2N)
/T527/HTX2P: D4.1 (IN1), D4.10 (NC), HDMI1.1 (D2+), U8.B25 (HTX2P)
/T527/HTXCN: D5.5 (IN4), D5.6 (NC), HDMI1.12 (CK-), U8.B28 (HTXCN)
/T527/HTXCP: D5.4 (IN3), D5.7 (NC), HDMI1.10 (CK+), U8.A28 (HTXCP)
/T527/LED-EN-A: U8.J7 (PE11), U13.18
/T527/LED-EN-B: U8.A2 (PE7), U24.18
/T527/LED-EN-C: U8.A3 (PE6), U25.18
/T527/LED-EN-D: U8.B1 (PE9), U26.18
/T527/MCSIA-CKN: U8.A10 (PK4), U13.8
/T527/MCSIA-CKP: U8.B10 (PK5), U13.9
/T527/MCSIA-D0N: U8.A12 (PK0), U13.2
/T527/MCSIA-D0P: U8.B12 (PK1), U13.3
/T527/MCSIA-D1N: U8.B11 (PK2), U13.5
/T527/MCSIA-D1P: U8.C11 (PK3), U13.6
/T527/MCSIB-CKN: U8.E8 (PK10), U24.8
/T527/MCSIB-CKP: U8.D8 (PK11), U24.9
/T527/MCSIB-D0N: U8.E12 (PK6), U24.2
/T527/MCSIB-D0P: U8.D12 (PK7), U24.3
/T527/MCSIB-D1N: U8.E10 (PK8), U24.5
/T527/MCSIB-D1P: U8.D10 (PK9), U24.6
/T527/MCSIC-CKN: U8.B7 (PK16), U25.8
/T527/MCSIC-CKP: U8.C7 (PK17), U25.9
/T527/MCSIC-D0N: U8.B9 (PK12), U25.2
/T527/MCSIC-D0P: U8.C9 (PK13), U25.3
/T527/MCSIC-D1N: U8.A8 (PK14), U25.5
/T527/MCSIC-D1P: U8.B8 (PK15), U25.6
/T527/MCSID-CKN: U8.A4 (PK22), U26.8
/T527/MCSID-CKP: U8.B4 (PK23), U26.9
/T527/MCSID-D0N: U8.A6 (PK18), U26.2
/T527/MCSID-D0P: U8.B6 (PK19), U26.3
/T527/MCSID-D1N: U8.A5 (PK20), U26.5
/T527/MCSID-D1P: U8.B5 (PK21), U26.6
/T527/MICIN3N: C199.2, U8.AF1 (MICIN3N)
/T527/MICIN3P: C200.2, U8.AF2 (MICIN3P)
/T527/PCIE0-CLKREQN: U8.C13 (PH19), U17.35 (B17_PRSNT#2)
/T527/PCIE0-PERSTN: R200.2, R201.2, U8.A16 (PH11), U17.11 (A11_PCIeRST)
/T527/PCIE0-WAKEN: U8.C15 (PH12), U17.29 (B11_WAKE#)
/T527/PCIE-CARD-PRESENT: R202.2, U8.L28 (PD20), U17.1 (A1_PRSNT#1)
/T527/PCIE-CLKN: C85.2, U8.C21 (PCIEREFCLKN)
/T527/PCIE-CLKP: C86.2, U8.B21 (PCIEREFCLKP)
/T527/PCIE-DN: C87.2, U8.B22 (PCIETX0-DN/USB)
/T527/PCIE-DP: C88.2, U8.A22 (PCIETX0-DP/USB)
/T527/PCIE-REF-CLKN: C85.1, U17.14 (A14_REFCLK-)
/T527/PCIE-REF-CLKP: C86.1, U17.13 (A13_REF_CLK+)
/T527/PCIE-RX0-DN: U8.C23 (PCIERX0-DN/US), U16.4 (A1p)
/T527/PCIE-RX0-DP: U8.B23 (PCIERX0-DP/US), U16.5 (A1n)
/T527/PCIE-SEL: C301.2, R197.1, R198.2, U8.L29 (PD21), U16.6 (SEL)
/T527/PCIE-TX0-DN: C87.1, U16.16 (A0p)
/T527/PCIE-TX0-DP: C88.1, U16.1 (A0n)
/T527/PI0: J1.18, U8.AH13 (PI0)
/T527/PI1: J1.22, U8.AG13 (PI1)
/T527/PI2: J1.24, U8.AL15 (PI2)
/T527/PI3: J1.23, U8.AN15 (PI3)
/T527/PI4: J1.19, U8.AM15 (PI4)
/T527/PI5: J1.21, U8.AJ15 (PI5)
/T527/PI6: J1.26, U8.AK15 (PI6)
/T527/PI7: J1.40, U8.AH15 (PI7)
/T527/PI8: J1.38, U8.AL16 (PI8)
/T527/PI9: J1.29, U8.AM16 (PI9)
/T527/PI10: J1.31, U8.AN17 (PI10)
/T527/PI11: J1.33, U8.AM17 (PI11)
/T527/PI12: J1.35, U8.AL17 (PI12)
/T527/PI13: J1.37, U8.AK17 (PI13)
/T527/PI14: J1.32, U8.AM18 (PI14)
/T527/PI15: J1.36, U8.AH17 (PI15)
/T527/PL2: J1.8, U8.AN7 (PL2)
/T527/PL3: J1.10, U8.AM6 (PL3)
/T527/PL5: J1.13, U8.AL7 (PL5)
/T527/PL6: J1.11, U8.AN8 (PL6)
/T527/PL7: J1.7, U8.AM8 (PL7)
/T527/PL8: J1.5, U8.AN9 (PL8)
/T527/PL9: J1.3, U8.AM9 (PL9)
/T527/PL10: J1.12, U8.AK9 (PL10)
/T527/PL11: J1.15, U8.AJ9 (PL11)
/T527/PL12: J1.28, U8.AK7 (PL12)
/T527/PL13: J1.27, U8.AJ7 (PL13)
/T527/PMU-SCK: R227.2, TP4.1 (1_1), U8.AN6 (PL0), U10.52 (SCK), U11.5 (SDA)
/T527/PMU-SDA: R228.2, TP3.1 (1_1), U8.AN5 (PL1), U10.51 (SDA), U11.6 (SCL)
/T527/POWER-EN-A: R169.2, U8.C2 (PE10), U13.17
/T527/POWER-EN-B: R170.2, U8.E6 (PE0), U24.17
/T527/POWER-EN-C: R171.2, U8.B3 (PE5), U25.17
/T527/POWER-EN-D: R172.2, U8.B2 (PE8), U26.17
/T527/PWR-EN: U8.AN4 (PM4), U19.12 (PWR_KEY)
/T527/SCL-A: R216.2, U8.C1 (PE12), U13.20
/T527/SCL-B: R218.2, U8.C4 (PE1), U24.20
/T527/SCL-C: R220.2, U8.E4 (PE3), U25.20
/T527/SCL-D: R222.2, U8.L7 (PE14), U26.20
/T527/SDA-A: R215.2, U8.G6 (PE13), U13.21
/T527/SDA-B: R217.2, U8.E5 (PE2), U24.21
/T527/SDA-C: R219.2, U8.C3 (PE4), U25.21
/T527/SDA-D: R221.2, U8.N7 (PE15), U26.21
/T527/SDC0-CLK: Card1.5 (CLK), U8.C19 (PF2)
/T527/SDC0-CMD: Card1.3 (CMD), U8.B19 (PF3)
/T527/SDC0-D0: Card1.7 (DAT0), U8.A20 (PF1)
/T527/SDC0-D1: Card1.8 (DAT1), U8.B20 (PF0)
/T527/SDC0-D2: Card1.1 (DAT2), U8.A18 (PF5)
/T527/SDC0-D3: Card1.2 (CD/DAT3), U8.B18 (PF4)
/T527/SDC0-DET: R196.2, U8.D20 (PF6)
/T527/SDC1-CLK: U8.R1 (PG0), U19.17 (SD_CLK)
/T527/SDC1-CMD: U8.R2 (PG1), U19.16 (SD_CMD)
/T527/SDC1-D0: U8.P3 (PG2), U19.18 (SD_D0)
/T527/SDC1-D1: U8.P2 (PG3), U19.19 (SD_D1)
/T527/SDC1-D2: U8.T3 (PG4), U19.14 (SD_D2)
/T527/SDC1-D3: U8.T2 (PG5), U19.15 (SD_D3)
/T527/SPI0_CLK: U2.6 (SCLK), U8.V31 (PC11)
/T527/SPI0_CS: U2.1 (~CS), U8.U29 (PC3)
/T527/SPI0_DI: U2.2 (SO(IO1)), U8.U28 (PC4)
/T527/SPI0_DO: U2.5 (SI(IO0)), U8.U30 (PC2)
/T527/SPI0_HOLD: R204.2, U2.7 (HOLD#(IO3))
/T527/SPI0_WP: R205.2, U2.3 (WP#(IO2))
/T527/USB1-DN: U8.E24 (USB1-DM), U22.14 (DMU)
/T527/USB1-DP: U8.D24 (USB1-DP), U22.15 (DPU)
/T527/USB2-DN: U8.E22 (USB2-DM), USB4.2 (D-)
/T527/USB2-DP: U8.D22 (USB2-DP), USB4.3 (D+)
/T527/VRA1: C338.2, U8.AG5 (VRA1)
/T527/VRA2: C339.2, U8.AG4 (VRA2)
/T527/VRP: C340.2, U8.AC7 (VRP)
/T527/WL-WAKE-AP: U8.AM3 (PM3), U19.13 (WL_HOST_WAKE)
/T527/X32KIN: C306.2, R206.1, U8.AM12 (X32KIN), X5.1 (OSC1)
/T527/X32KOUT: C307.2, R206.2, U8.AM11 (X32KOUT), X5.2 (OSC2)
/display/AUX_CH_N: C208.2, D9.2 (IN2), D9.9 (NC), DP1.17 (AUX_CH_N), R108.1
/display/AUX_CH_P: C207.2, D9.1 (IN1), D9.10 (NC), DP1.15 (AUX_CH_P), R107.1
/display/ML_LANE0_N: C135.2, D7.2 (IN2), D7.9 (NC), DP1.3 (ML_LANE0_N)
/display/ML_LANE0_P: C134.2, D7.1 (IN1), D7.10 (NC), DP1.1 (ML_LANE0_P)
/display/ML_LANE1_N: C137.2, D7.5 (IN4), D7.6 (NC), DP1.6 (ML_LANE1_N)
/display/ML_LANE1_P: C136.2, D7.4 (IN3), D7.7 (NC), DP1.4 (ML_LANE1_P)
/display/ML_LANE2_N: C139.2, D8.2 (IN2), D8.9 (NC), DP1.9 (ML_LANE2_N)
/display/ML_LANE2_P: C138.2, D8.1 (IN1), D8.10 (NC), DP1.7 (ML_LANE2_P)
/display/ML_LANE3_N: C141.2, D8.5 (IN4), D8.6 (NC), DP1.12 (ML_LANE3_N)
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

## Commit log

2025-03-13 created initial sheets
    chose sheets and components.
    [Artificer A1 Board Rev 0.1.kicad_pcb, audio.kicad_sch, camera.kicad_sch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]
2025-04-15 schematic update
    [LPJG0926HENL.step, ethernet.kicad_sch, pcie.kicad_sch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]
2025-04-15 localized libraries
    [LPJG0926HENL.step, audio.kicad_sch, display.kicad_sch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]
2025-04-18 dc-dc & started eth PHY
    [ethernet.kicad_sch, power.kicad_sch, processor.kicad_sch]
2025-04-24 added a few accessories
    [display.kicad_sch, dram.kicad_sch, ethernet.kicad_sch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]
2025-04-29 added HDMI, DP, DSI, etc
    [audio.kicad_sch, display.kicad_sch, ethernet0.kicad_sch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]
2025-05-09 finished dram
    [dram.kicad_sch, mipi camera.kicad_sch, processor.kicad_sch]
2025-05-14 Create Hierarchical schematic.jpg
2025-08-04 edited simulations
    [wifi&bt.kicad_sch]
2025-08-26 added: sd, wifi, audio, started power, fixed buses
    [Artificer A1 Board Rev 0.1.kicad_sch, audio.kicad_sch, ethernet0.kicad_sch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]
2025-09-06 added features
    [Artificer A1 Board Rev 0.1.kicad_sch, display.kicad_sch, dram.kicad_sch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]
2025-09-23 finished rough draft of power supply circuitry!
    Yay! This one took a while
    [ethernet0.kicad_sch, ethernet1.kicad_sch, pcie.kicad_sch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]
2026-08-19 cleaned up, kicad 10 & usb c pd
    migrated to Kicad 10,
    added USB PD for power input
    added capacitors inductors and resistor footprints
    [Artificer A1 Board Rev 0.1.kicad_sch, T527 power.kicad_sch, audio.kicad_sch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]
2026-08-19 added gitignore
    [Artificer A1 Board Rev 0.1.kicad_sch]
2026-08-29 placed all components
    [Artificer A1 Board Rev 0.1.kicad_pcb, Artificer A1 Board Rev 0.1.kicad_sch, audio.kicad_sch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]
2026-09-02 started routing
    [Artificer A1 Board Rev 0.1.kicad_pcb, Artificer A1 Board Rev 0.1.kicad_sch, audio.kicad_sch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]
2026-09-04 finsihed more routing
    [Artificer A1 Board Rev 0.1.kicad_pcb, Artificer A1 Board Rev 0.1.kicad_sch, pcie&usb3.kicad_sch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]
2026-09-10 more routing and decoupling
    [Artificer A1 Board Rev 0.1.kicad_pcb, Artificer A1 Board Rev 0.1.kicad_sch, T527 power.kicad_sch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]
2026-09-10 revert back to this version if reroute fails
    [Artificer A1 Board Rev 0.1.kicad_pcb]
2026-09-11 now the board is more manufacturable
    [Artificer A1 Board Rev 0.1.kicad_pcb, processor.kicad_sch]
2026-09-13 finished ddr4 and gpio
    [Artificer A1 Board Rev 0.1.kicad_pcb, Artificer A1 Board Rev 0.1.kicad_sch]
2026-09-13 finished bga decoupling placement
    [Artificer A1 Board Rev 0.1.kicad_pcb]
2026-09-16 worked on power pours
    [Artificer A1 Board Rev 0.1.kicad_pcb, audio.kicad_sch, display.kicad_sch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]
2026-09-17 finished most of the power
    [Artificer A1 Board Rev 0.1.kicad_pcb, power.kicad_sch, processor.kicad_sch]
2026-09-18 more power changed mipi csi and dis to aux 3.3V
    [Artificer A1 Board Rev 0.1.kicad_pcb, ethernet0.kicad_sch, power input.kicad_sch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]
2026-09-22 3.3V Aux & 12V power
    [Artificer A1 Board Rev 0.1.kicad_pcb]
2026-09-22 getting closer
    [Artificer A1 Board Rev 0.1.kicad_pcb]
2026-09-23 added power and gnd vias
    [Artificer A1 Board Rev 0.1.kicad_pcb, T527 power.kicad_sch, pcie&usb3.kicad_sch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]
2026-09-29 cleaned up 5V power plane
    [Artificer A1 Board Rev 0.1.kicad_pcb]
2026-10-13 added fan and PD debugging circuitry
2026-10-20 added silkscreen info and paste section to EPs
2026-10-21 adjusted custom clearance rules, mounting holes and traces
2026-10-29 optimized copper pour, added LEDs
2026-10-29 moved 4x mipi cameras to improve diff pair spacing
2026-10-30 finished DDR4 trace length tuning
2026-11-04 antenna opt. and outer GND stitching vias
2026-11-04 removed PCB way
2026-11-05 cleaned up BOM
